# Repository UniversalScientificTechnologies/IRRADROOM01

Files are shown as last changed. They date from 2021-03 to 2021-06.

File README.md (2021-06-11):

# IRRADROOM01
Systém byl vyvinut firmou [Universal Scientific Technologies s.r.o.](https://www.ust.cz)

# Návod k použití
_Uživatel zařízení by měl vždy postupovat podle tohoto návodu a neměl by zařízení nechávat bez dozoru nebo k němu pouštět uživatele neseznámené s touto příručkou._

## Popis zařízení
Řidící systém ozařovny IRRADROOM01 slouží pro ovládání zařízení umístěných v ozařovně [ODZ ÚJF AV ČR](http://www.ujf.cas.cz/cs/oddeleni/oddeleni-dozimetrie-zareni/). Systém se skládá z následujících komponent:

 * Řídící počítač
 * Ovládací terminál u vstupních dveří
 * Webové rozhraní pro přípravu experimentů
 * Stínící krabice s dvojicí zářičů
 * Motorový mechanizmus pro vytažení zářiče ze stínící krabice
 * Čtyřmístný display pro zobrazení vzdálenosti stolu pro vzorky
 * Senzor zavřených vstupních dveří
 * Senzor polohy zdrojů (zářičů)

Cílem celého systému je zbezpečnit a zjednodušit práci s ozařovnou a jejím vybavením. Cílem je, aby kdokoliv nemohl otevřít zářič nebo ho nechat vytáhnutý ze stínící krabice. 
Systém funguje tak, že uživatel si ve webovém prostředí přípraví program. K němu si vygeneruje pin pro jedno spuštění programu. Následně zkontroluje umístění vzorku v ozařovně, vyloučí přítomnost osob v místnosti a z terminálu u vstupních dveří spustí program, který se postupně vykoná. 

## Webové rozhraní
Webové rozhraní poskytuje rozhraní pro přístup pro správu a nastavování jednotlivých programů a pro získávání dat z nich. 

### Tvorba programu
na podstránce `/controller` naleznete formulář pro tvorbu programu. V sekci `Programy ozařovny` jsou vypsané všechny vytvořené programy. Nový program lze vytvořit kliknutím na modré tlačítko vytvořit nový program. Tím se otevře okno pro sestavení programu. V horní části jsou vidět jednotlivé kroky. Po vytvoření nového programu se zde nachází pouze `Start` a `Konec`.

Nový krok se přidá tak, že se ze seznamu možných kroků vybere požadovaný krok. K němu se přiřadí délka trvání v sekundách a pořadí. Pokud přidáváme první krok, nemusíme položku pořadí měnit.

## Terminál
Terminál je zařízení vybavené dotykovou obrazovkou sloužící k základnímu zobrazení stavu systému a pro spouštění jednotlivých běhů programů. Terminál je umístěn u vstupních dveří do ozařovny. Tak, aby uživatel viděl, jestli vstup do místnosti je bezpečný a aby při spouštění programu mohl zkontrolovat, jestli se v místnosti nikdo nenachází. 

Na vrchní straně terminálu se vždy nachází název zařízení, který je zároveň tlačítkem pro znovu-načtení stránky. To může být řešením některých technických potíží. Během běžného provozu by nemělo být používáno. 

Za názvem zařízení je kroužek, který ukazuje stav připojení terminálu k řídícímu počítači. Prázdný kroužek zobrazuje nezinicializovaný terminál. Pokud je v kroužku křížek, tak byl terminál odpojený nebo se nedokázal přípojit k řídícímu počítačí. Kroužek s fajfkou zobrazuje připojený terminál. 

Následuje aktuální čas terminálu a v pravé časti jsou tři tlačítka, která 

### Domů
Úvodní stránka terminálu poskytuje přehled o stavu dílčích částí systému. 

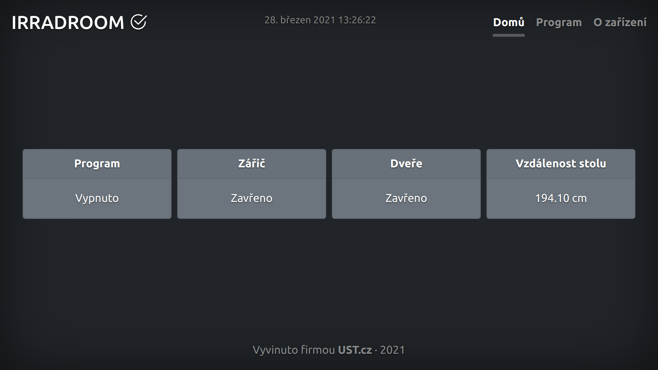
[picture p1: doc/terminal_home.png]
Domaci stranka terminalu


##### Pogram
Popisuje, jestli je v zařízení spuštěný nějaký program nebo ne. V případě, že program běží, tlačítko je zelené a je tam napsán aktuální krok programu. 

##### Zářič
Ukazuje v jakém poloze je umístěn zářič. Díky tomu uživatel pozná, jestli je bezpečné do místnosti vstoupit nebo ne. 

##### Dveře
Stav vstupních dveří. Červený panel ukazuje otevřený stav. 

##### Vzdálenost stolu
Zobrazuje aktuální vzdálenost lavice se vzorky od zářiče. 

### Program
Záložka  program  slouží ke spuštění programu na základě pinu, který uživatel získá ve webovém rozhraní. V základním stavu je v této záložce zobrazená pouze klávesnice pro zadání pinu. Klávesnice je vybavena dvojicí dodatkových tlačítek. Červené tlačítko slouží ke smazání posledního znaku. Zelené tlačítko slouží pro odeslání pinu. Pokud je pin správný, otevře se náhled programu tohoto pinu. V jiném případě je zobrazena chybová hláška o nenalezeném programu. 

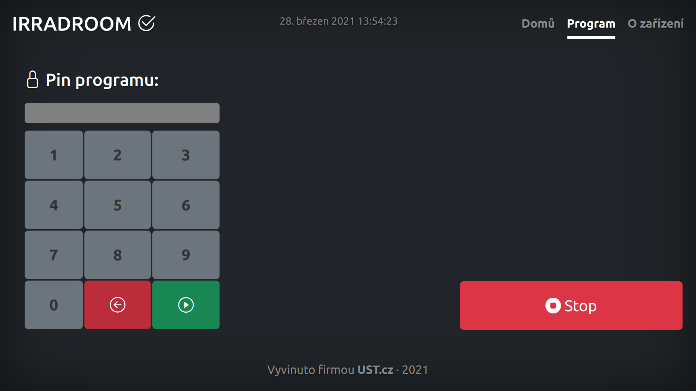
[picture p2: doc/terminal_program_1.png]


V druhém kroku se vám zobrazí přehled zvolného programu. Je zde zobrazený název programu. Jeho autor a autor spuštění programu. Dále odhad času a jednotuvé kroky. 
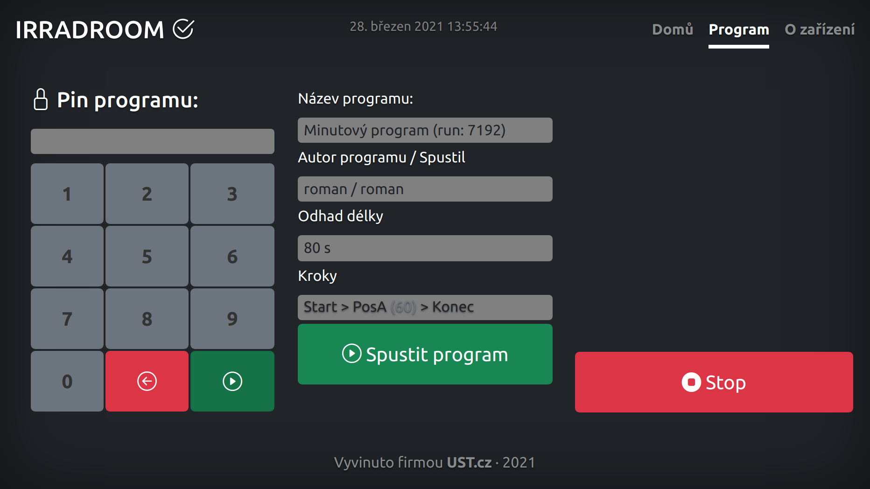
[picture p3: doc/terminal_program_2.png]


V pravém sloupci pak vidíte samotý průběh programu. 
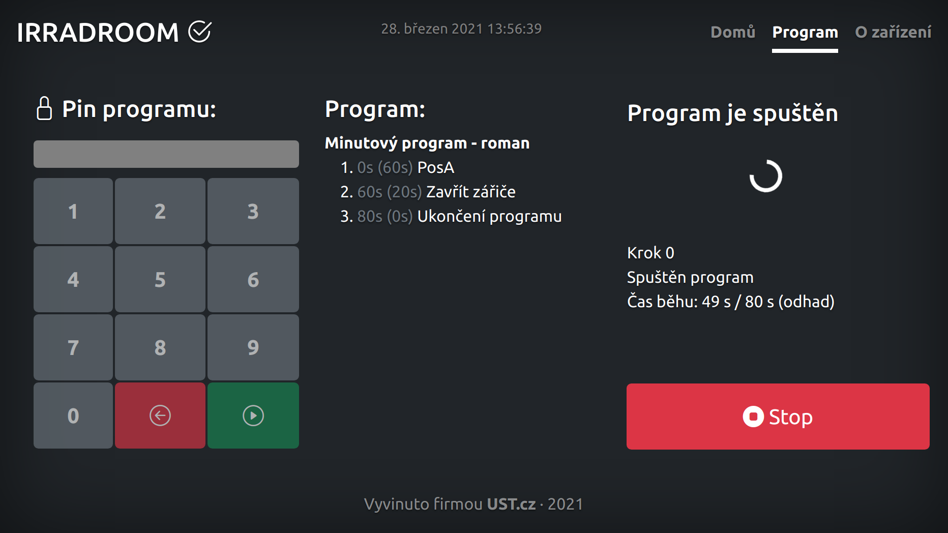
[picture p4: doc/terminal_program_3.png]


### O zařízení
V poslední záložce terminálu uživatel nalezne popis terminálu a QR kód s odkazem a tento návod. 

## Tvorba nových užívatelů. 
Tvorba nových uživatelů se neprovádí přes webové rozhraní. Pro tento účel existuje python skript, který vytvoří nového uživatele. Pokud uživatel již existuje, bude provedena jeho aktualizace. Skript se spouští příkazem `python3 update_user.py`. 

```bash
# python3 update_user.py
usage: update_user.py [-h] --login LOGIN --passw PASSW --name NAME
```

_Aby vaše heslo nezůstalo v historii bashe, před příkaz vložte ` ` (mezeru)._

## Technické detaily
### Řidící počítač

* Odroid C2
* Ubuntu 20.04.4 minimal ()
* ROS 2 Foxy; Debain binaries (https://index.ros.org/doc/ros2/Installation/Foxy/Linux-Install-Debians/)
  * ros-foxy-ros-base
* `sudo apt install git htop nano mc python3-colcon-common-extensions   `
* `pip3 install serial tornado pymongo  `
* Pymlab, i2c-tools (fork)
* Create ROS2 WS
* Setup enviroment
* `export ROS_DOMAIN_ID=35`
* Install `rosbridge_server` (from git; branch `ros2`)

### Schéma zařízení
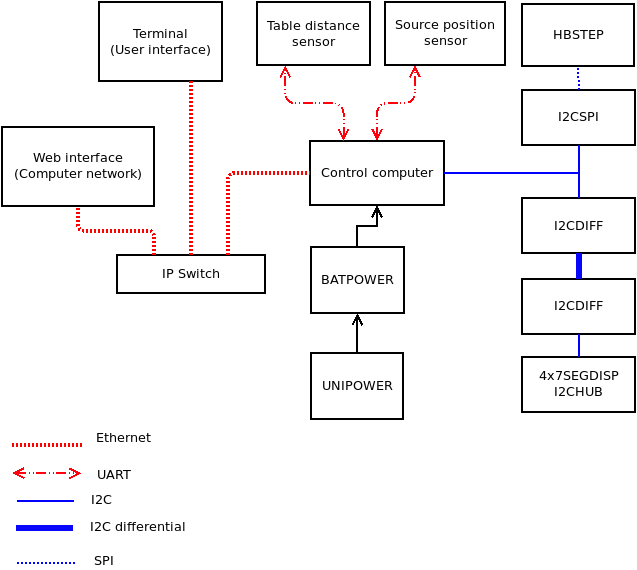
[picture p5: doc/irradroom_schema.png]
Schéma zařízení


#### ROS 2
Jako základní framework je použit ROS2. Domain ID je nastaveno na 35 v `~/.bashrc`.

#### IP adresy:
Terminál:
``` *.*.*.79```
Řídící počítač:
```*.*.*.80```

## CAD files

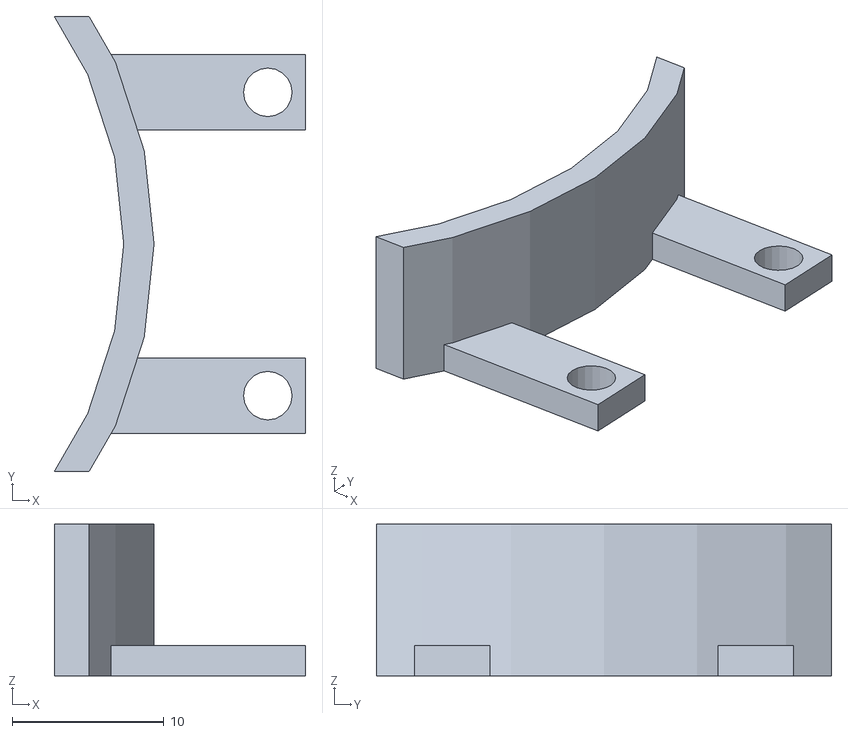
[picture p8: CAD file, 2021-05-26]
CAD/drzak_TOF.stl
16.6 x 30.0 x 10.0

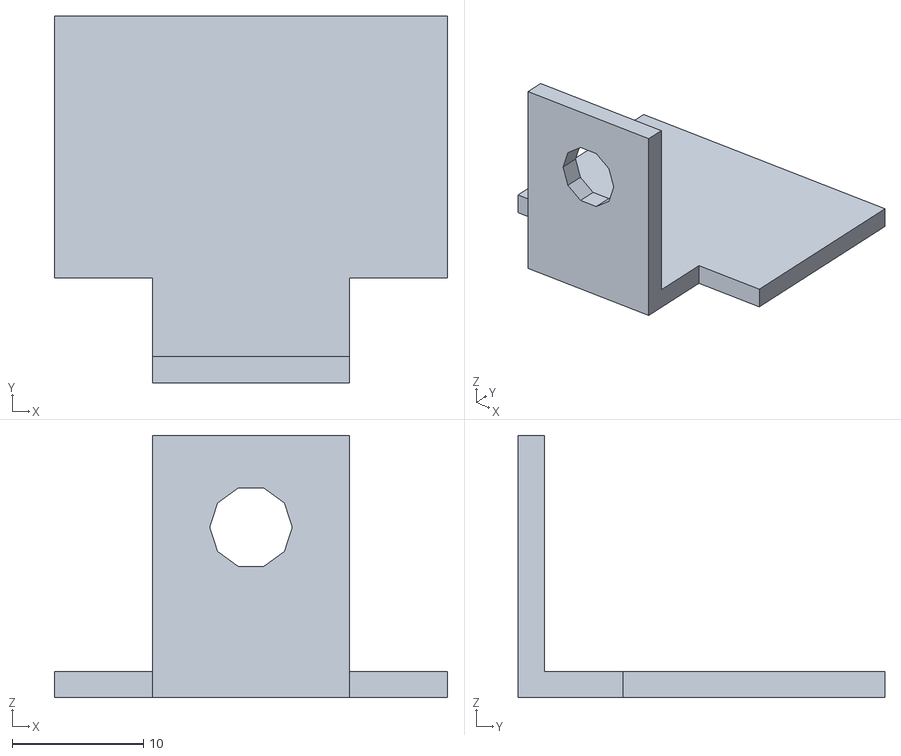
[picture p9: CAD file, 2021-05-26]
CAD/odrazna_plocha.stl
30.0 x 28.0 x 20.0

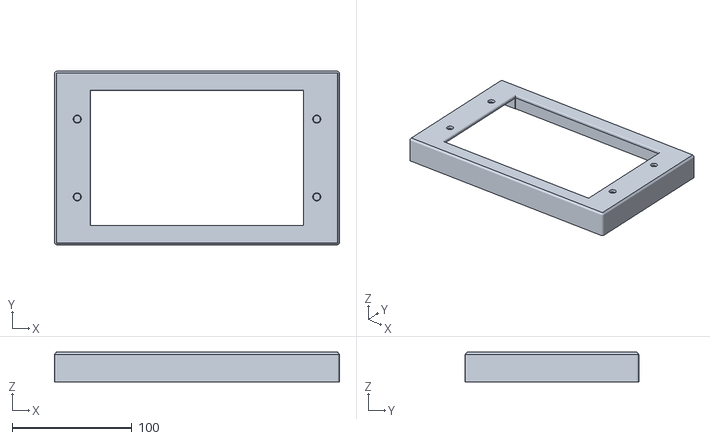
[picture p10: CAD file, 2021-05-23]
CAD/ramecek.stl
238.0 x 145.0 x 25.0

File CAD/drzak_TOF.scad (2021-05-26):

intersection(){
    translate([-59/2, 0, 0]) difference(){
        cylinder(d=55+4, h=10);
        cylinder(d=55, h=11);
    }
    cube(30, center=true);
}

difference(){
for(y = [-10, 10])
    translate([-3, y-5/2, 0])
        cube([13, 5, 2]);
for(y = [-10, 10])
    translate([15/2, y, -1])
        cylinder(d=3.2, h=10, $fn=20);
}

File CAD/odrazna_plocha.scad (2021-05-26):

translate([-30/2, 8, 0]) cube([30,20, 2]);
translate([-15/2, 0, 0]) cube([15,20, 2]);
difference(){
translate([-15/2, 0, 0]) cube([15,2, 20]);
    
translate([0, 0, 13]) rotate([90, 0, 0])cylinder(d=6.3, h=10, center=true);
}

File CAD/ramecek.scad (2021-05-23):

diry_x = 200;
diry_y = 65;

ramecek_x = 238;
ramecek_y = 145;
ramecek_d = 25;

M3_screw_diameter = 3.3;
M3_nut_diameter = 5.8;
M3_head_height = 2.8;

lcd_x = 178;
lcd_y = 113;

term_x = 199;
term_y = 140;
term_d = ramecek_d-3;
$fn=40;

difference(){
        
    minkowski(){
        translate([0, 0, (ramecek_d-2)/2]) cube([ramecek_x-4, ramecek_y-4, ramecek_d-2], center=true);
        union(){
            cylinder(d1=4, d2=1, h=2, $fn=50);
        }
    }
    
    for(x=[-0.5, 0.5]*diry_x, y=[-0.5, 0.5]*diry_y)
        translate([x, y, 0])
            union(){
                translate([0, 0, -0.1])
                    cylinder(d=M3_screw_diameter, h=ramecek_d-M3_head_height+0.1+0.15);
                translate([0, 0, ramecek_d-M3_head_height+0.3])
                    cylinder(d=M3_nut_diameter, h=10);
                translate([0, 0, ramecek_d-1+0.31])
                    cylinder(d1=M3_nut_diameter, d2=M3_nut_diameter+1, h=0.7);
            }
     cube([lcd_x, lcd_y, 50], center=true);
     translate([0, 0, ramecek_d+4.5])
        minkowski(){
            cube([lcd_x, lcd_y, ramecek_d/2-2], center=true);
            cylinder(d1=0, d2=2, h=1);
        }
     
     translate([0, 0, term_d/2]) cube([term_x, term_y, term_d], center=true);
     
     
     translate([0, 0, (ramecek_d-10)/2-0.1]) cube([ramecek_x-7, ramecek_y-7, ramecek_d-10], center=true);
     translate([0, 0, (ramecek_d-4)/2]) cube([ramecek_x-7, ramecek_y/3, ramecek_d-4], center=true);
     translate([0, 55, (ramecek_d-4)/2]) cube([ramecek_x-7, ramecek_y/5, ramecek_d-4], center=true);
     translate([0, -55, (ramecek_d-4)/2]) cube([ramecek_x-7, ramecek_y/5, ramecek_d-4], center=true);
}

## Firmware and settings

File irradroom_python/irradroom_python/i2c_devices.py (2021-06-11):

import rclpy
import serial
import time
from rclpy.node import Node

import time
import datetime
import sys
from pymlab import config
from pymlab.helpers.LED7SEG01A_array import LED7SEG01A_array
import axis


from std_msgs.msg import String
from std_msgs.msg import Int8
from std_msgs.msg import Int32
from sensor_msgs.msg import Range

from threading import Lock

steps = 13000
source_closed = (120, 130)

class I2C_devices(Node):

    def __init__(self):
        super().__init__("i2c_devices")
        self.subscription_dist = self.create_subscription(Range, "distance", self.distance_callback, 10)
        self.subscription_source_position = self.create_subscription(Range, "source_position", self.source_position_callback, 10)
        self.subscription_raw_move = self.create_subscription(Int32, "raw_move", self.raw_move_callback, 10)
        self.subscription_motor_position = self.create_subscription(String, "motor_cmd", self.motor_position_callback, 10)
        self.subscription_door_position = self.create_subscription(Int8, "door_status", self.door_position_callback, 10)

        self.publisher = self.create_publisher(Int8, "source_position_status", 10)

        self.i2c_initialized = False
        self.motor_position_valid = False
        self.motor_communication = True

        self.logger = self.get_logger()

        self.i2c_lock = Lock()

        self.i2c_init()

        timer = 1
        self.timer = self.create_timer(timer, self.loop)
        self.i = 0

        self.declare_parameter('source_position_min', 25)
        self.declare_parameter('source_position_max', 25+150)
        self.declare_parameter('source_position_center', 15+150/2)
        self.declare_parameter('source_position_A', 25+20)
        self.declare_parameter('source_position_B', 25+150-20)

        #self = self.get_parameter('my_str')

        self.distance = 0
        self.distance_update = False
        self.last_door = 1

    def i2c_init(self):

        self.i2c_lock.acquire()

        port = 1
        cfg = config.Config(
            i2c = {
                "port": port,
            },
            bus = [
                {
                "type": "i2chub",
                "address": 0x70,

                "children": [
                    {"name": "pca9635_1", "type": "PCA9635", "channel": 0},
                    {"name": "pca9635_2", "type": "PCA9635", "channel": 1},
                    {"name": "pca9635_3", "type": "PCA9635", "channel": 2},
                    {"name": "pca9635_4", "type": "PCA9635", "channel": 3},
                ],
                },
                {
                    "name":"spi",
                    "type":"i2cspi"
                },

            ],
        )
        cfg.initialize()

        self.spi = cfg.get_device("spi")
        self.spi.SPI_config(self.spi.I2CSPI_MSB_FIRST| self.spi.I2CSPI_MODE_CLK_IDLE_HIGH_DATA_EDGE_TRAILING |self.spi.I2CSPI_CLK_461kHz)
        self.spi.GPIO_config(self.spi.I2CSPI_SS2 | self.spi.I2CSPI_SS3, 0x50)

        self.motor = axis.axis(SPI = self.spi, SPI_CS = self.spi.I2CSPI_SS0, StepsPerUnit=1)
        self.motor.setConfig(F_PWM_INT = None, F_PWM_DEC = None, POW_SR = None, OC_SD = None, RESERVED = None, EN_VSCOMP = None, SW_MODE = None, EXT_CLK = None, OSC_SEL = None)
        self.motor.Setup(MAX_SPEED = 500, KVAL_ACC=0.6, KVAL_RUN=0.6, KVAL_DEC=0.6, ACC = 800, DEC = 2000, FS_SPD=0, STEP_MODE=axis.axis.STEP_MODE_FULL)

        #self.motor.setMaxSpeed(speed = 500)
        #self.motor.setMinSpeed(speed = 10*16, LSPD_OPT = True)

        n1 = cfg.get_device("pca9635_1")
        n2 = cfg.get_device("pca9635_2")
        n3 = cfg.get_device("pca9635_3")
        n4 = cfg.get_device("pca9635_4")

        time.sleep(0.5)

        self.disp = LED7SEG01A_array([n1, n2, n3, n4])

        self.i2c_initialized = True
        print("I2C init done")

        #self.motor.GoTo(int(200*8*50))
        #self.motor.Move(200, direction = 0)
        self.motor.setPosition(steps*0.5)
        self.motor_position_valid = True

        self.motor_communication = False
        self.i2c_lock.release()



    def distance_callback(self, data):
        self.distance = data.range
        self.distance_update = True
        #print("update_distance", self.distance)
        text = "{}   ".format(int(self.distance))
        print("dist", text)
        if self.i2c_initialized:
            self.i2c_lock.acquire()
            if self.last_door:
                self.disp.set_text(text+"  ")
            else:
                self.disp.set_text("     ")
            self.i2c_lock.release()

    def source_position_callback(self, data):
        print("source position", data.range)
        if data.range < source_closed[0]:
            self.send_source_position(-1)
        elif data.range > source_closed[1]:
            self.send_source_position(1)
        else:
            self.send_source_position(0)


        if self.i2c_initialized and not self.motor_position_valid:
            self.i2c_lock.acquire()
            
            self.motor.Float()
            time.sleep(1)
            print("Nastavuji polohu motoru ze senzoru: {}mm -> {}units".format(data.range, data.range*50*100))
            #self.motor.setPosition(steps*data.range)
            self.motor_position_valid = True

            self.i2c_lock.release()
            #self.move_motor('stop')


    def door_position_callback(self, data):
        current_door = data.data
        print("Dvere", current_door)
        if not self.last_door and current_door:
            print("Dvere otevrene")
            #if self.i2c_initialized and not self.motor_position_valid:
            self.last_door = current_door
            self.move_motor("stop")

        if self.last_door != current_door:
            self.last_door = current_door
            print("Zmena stavu dveri")
            if current_door:
                self.spi.GPIO_write(0xFB)
            else:
                self.spi.GPIO_write(0xFD)
    
    def send_source_position(self, position):
        msg = Int8()
        msg.data = int(position)
        print(int(position), msg)
        self.publisher.publish(msg)


    def move_motor(self, pos):
        print("Move motor", pos)
        if pos == "posA":
            self.i2c_lock.acquire()
            print("Posouvam motor na A")
            self.motor.Float()
            self.motor.Wait()
            #self.motor.GoTo((25+20)*steps)
            self.motor.GoTo(0)
            self.i2c_lock.release()
            #self.send_source_position(-1)

        elif pos == "posB":
            self.i2c_lock.acquire()
            print("Posouvam motor na B")
            self.motor.Float()
            self.motor.Wait()
            #self.motor.GoTo((25+150-20)*steps)
            self.motor.GoTo(steps)
            self.i2c_lock.release()
            #self.send_source_position(1)

        elif pos == "stop":
            self.i2c_lock.acquire()
            print("Posouvam motor DOMU")
            self.motor.Float()
            self.motor.Wait()
            self.motor.GoTo(steps/2)
            self.i2c_lock.release()
            #self.send_source_position(-1)

        elif pos == "float":
            self.i2c_lock.acquire()
            print("Vypinam motor")
            self.motor.Float()
            self.i2c_lock.release()
        
        print("pozice nastavena ")
        self.last_motor_operation = time.time()
    

    def motor_position_callback(self, data):
        d = data.data
        self.logger.info("MotorPositionCallback: {}".format(d))

        d = data.data
        if "set_center" in d:
            print("Set center")
            self.i2c_lock.acquire()
            self.motor.Float()
            time.sleep(1)
            self.motor.setPosition(steps*0.5)
            self.motor_position_valid = True
            self.i2c_lock.release()

        elif "posA" in d:
            print(d, "<<<")
            self.move_motor("posA")
        elif "posB" in d:
            print(d, "<<<")
            self.move_motor("posB")
        elif "stop" in d:
            print(d, "<<<")
            self.move_motor("stop")
        elif "float" in d:
            print(d, "<<<")
            self.move_motor("float")

    def raw_move_callback(self, data):
        steps = data.data
        print("RAW MOVE", data)
        self.motor.Move(steps, direction = 0)

    def loop(self):
        self.i2c_lock.acquire()
        status = self.motor.getStatus()
        #print(status)
        #print("Position HBSTEP>>>", status.get('POSITION', 0)/(steps))
        self.i2c_lock.release()
        #self.send_source_position()


def main(args=None):
    rclpy.init(args=args)
    i2c = I2C_devices()
    rclpy.spin(i2c)

    i2c.destroy_node()
    rclpy.shutdown()

if __name__ == '__main__':
    main()

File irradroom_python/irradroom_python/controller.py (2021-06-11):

import rclpy
import serial
import time, datetime
import pymongo
from bson.json_util import dumps
import bson
from rclpy.node import Node
import sched, time

from std_msgs.msg import String, Int8
from sensor_msgs.msg import Range
from irradroom_cmake.msg import ProgramStatus

from irradroom_cmake.srv import RunProgram

class Controller(Node):

    def __init__(self):
        super().__init__("range_measurer")
        #self.publisher = self.create_publisher(Range, "distance", 10)

        self.mdb = pymongo.MongoClient("mongodb://localhost:27017/").IRRADROOM
        
        self.srv = self.create_service(RunProgram, 'run_program', self.run_program_callback)

        self.pub_program_status = self.create_publisher(ProgramStatus, "program_status", 10)
        self.pub_motor_position = self.create_publisher(String, "source_position_status", 10)
        self.subscription_door_position = self.create_subscription(Int8, "door_status", self.door_position_callback, 10)
        self.pub_motor_cmd = self.create_publisher(String, "motor_cmd", 10)


        self.timer = self.create_timer(0.1, self.loop)
        self.timer2 = self.create_timer(0.5, self.loop_send)
        
        print("Controller spusten")

        self.door = 1 

        self.actual_run = None
        self.actual_info = {}
        self.actual_program = None
        self.actual_step = 0
        self.actual_start = 0
        self.actual_message = ''

        self.scheduler = sched.scheduler(time.time, time.sleep)
        self.logger = self.get_logger()


    def loop(self):
        self.scheduler.run(blocking=False)

    def loop_send(self):
        self.send_program_status()


    def send_program_status(self):
        msg = ProgramStatus()
        run = bool(self.actual_run)
        msg.program_status = int(run)
        msg.message = self.actual_message

        if run:
            msg.run_id = str(self.actual_info.get('name', self.actual_run))
            msg.step = self.actual_step
            msg.start = int(self.actual_start)
            msg.duration = int(time.time() - self.actual_start)
        self.pub_program_status.publish(msg)


    def send_motor_cmd(self, cmd):
        msg = String()
        msg.data = cmd
        self.pub_motor_cmd.publish(msg)

    def do_step(self, job = None, step = -1):

        step = int(step)
        self.logger.info("Do step {}, {}".format(step, job))

        self.actual_step = step+1

        self.send_program_status()

        if job == 'sleep':
            return True

        elif job == 'PosA':
            self.send_motor_cmd('posA')
            print("Move to A")

        elif job == 'PosB':
            self.send_motor_cmd('posB')
            print("Move to B")

        elif job == 'stop':
            self.send_motor_cmd('stop')
            print("Move to A")

        elif job == 'end':
            self.send_motor_cmd('stop')
            #self.actual_run = None
            self.scheduler.enter(20, 1, self.do_step, kwargs={'job': 'end_program', 'step': -1})
            self.actual_message = "Ukončuji program"
            print("Konec!")

        elif job == 'set_center':
            self.send_motor_cmd('set_center')

        elif job == 'end_program':
            self.actual_run = None
            self.send_motor_cmd('float')
            self.actual_message = ''



    def run_program(self, run_key, run_id):
        program = list(self.mdb.runs.find({'run_key': int(run_key) }))
        if len(program) > 0:
            program = program[0]

        # Iniciovat promenne
        self.actual_run = program['_id']
        self.actual_info = program
        self.actual_program = program['job']
        self.actual_step = 0
        self.actual_start = int(time.time())
        self.actual_message = "Načítám program"

        delay = 0

        # Naplanovat jednotlive kroky programu
        for i, step in enumerate(self.actual_program):
            print(i, "Udelat", step['operation'], "za", delay)
            self.scheduler.enter(delay, 2, self.do_step, kwargs={'job': step['operation'], 'step': i})
            delay += float(step['duration'])

        # Vzdy provest ukonceny
        self.scheduler.enter(delay+1, 1, self.do_step, kwargs={'job': 'end', 'step': len(self.actual_program)+0})
        print(len(self.actual_program), "Udelat", 'end', "za", delay+1)
        
        self.actual_message = "Spuštěn program"

        

    def run_program_callback(self, request, response):
        self.logger.info("CALLBACK - RUN PROGRAM")
        self.logger.info(request.run_id)
        self.logger.info(request.run_key)

        if request.run_id == '' and request.run_key == '':
            self.cancel_program()

            response.start_status = -2
            response.message = "Program cancelled"
            return response
        
        if self.door:    
            response.start_status = -3
            response.message = "Dvere otevreny"
            return response

        if self.actual_run:
            response.start_status = -1
            response.message = "Neco uz bezi"
            return response


        program = list(self.mdb.runs.find({'run_key': int(request.run_key) }))
        if len(program) > 0:
            program = program[0]
        else:
            response.start_status = -4
            response.message = "Prazdny program"
            return response

        # Spustit program
        self.get_logger().info(str(program))
        self.run_program(program['run_key'], program['_id'])

        response.start_status = 1
        response.message = "Spouštím tento program" 
        return response

    # Vymazat vsechny kroky v rade
    def cancel_program(self):
        self.scheduler = sched.scheduler(time.time, time.sleep)
        self.do_step('end')

    def door_position_callback(self, msg):
        door = msg.data
        self.door = door

        if door and self.actual_run:
            self.cancel_program()



def main(args=None):
    rclpy.init(args=args)
    rm = Controller()
    rclpy.spin(rm)

    rm.destroy_node()
    rclpy.shutdown()

if __name__ == '__main__':
    main()

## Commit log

2017-04-26 driver na cteni dalkomeru
2021-03-09 irrad source position sensor
2021-03-12 Uprava driveru dalkomeru
2021-03-28 uprava driveru
2021-05-23 add CAD files
    [ramecek.scad, ramecek.stl]
2021-05-24 Adding gcode used for printing.
2021-05-26 pridani odrazne plochy
    [odrazna_plocha.scad, odrazna_plocha.stl]
2021-05-26 drzak tof
    [drzak_TOF.scad, drzak_TOF.stl]
